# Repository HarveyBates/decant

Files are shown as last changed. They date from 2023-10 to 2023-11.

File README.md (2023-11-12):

# Decant

CAN-to-USB analyser. Designed to plug into existing CAN infrastructure for analysis. Focused on CANopen. UI is a work in progress.

## Hardware

<div>
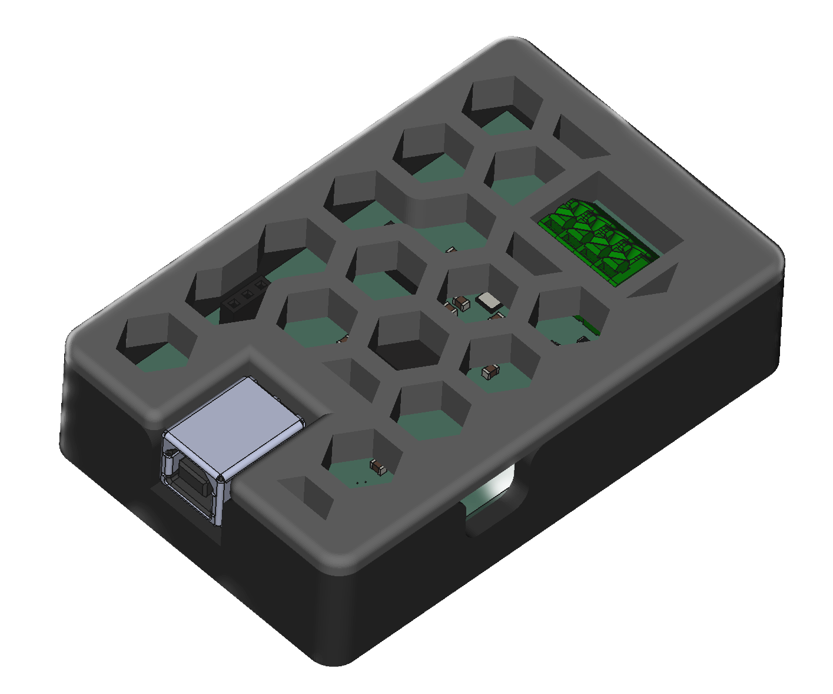
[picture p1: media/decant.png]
  
</div>

### Electronics
- [x] STM32F4 based processor
- [x] Two CAN interfaces with MCP2562 trancievers
- [x] USB powered
- [ ] Breakout other pins for various other functions
- [ ] Reduce footprint

#### BOM
See [BOM](electronics/bom/decant.csv), roughly $40 AUD ($25 USD). Main cost is the processor, however, this is the lowest cost STM32 that features 
CAN and USB on seperate pins.

#### PCB
See `electronics/decant/gerber` for [gerber files](https://github.com/HarveyBates/decant/tree/main/electronics/decant/gerber) 
that can be zipped and uploaded to a PCB manufactuer of choice. Get a top layer stencil too as this will make assembly easier.

## UI

This is a work in progress, currently using [Qt](https://www.qt.io/). Below is a TODO list to make it more functional.

<div>
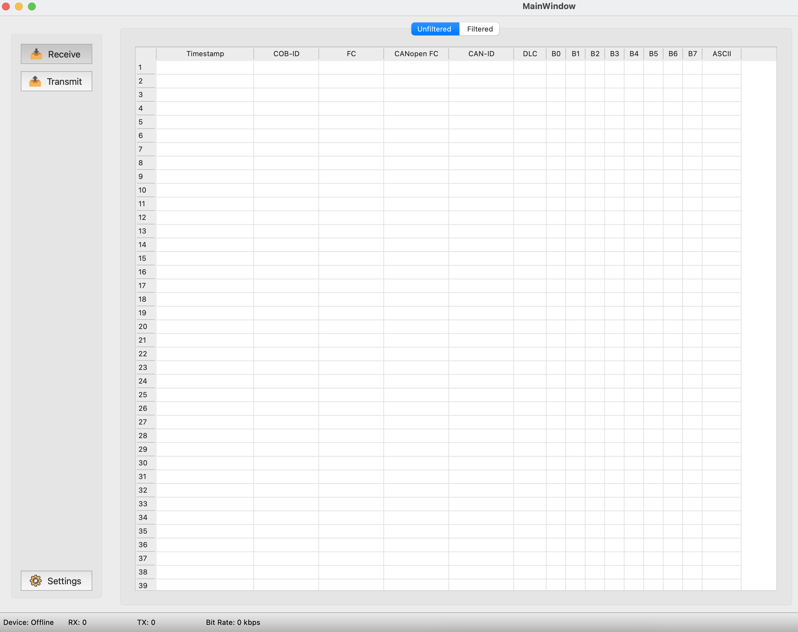
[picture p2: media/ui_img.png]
  
</div>

### Base functions
- [x] Read raw CAN messages to table
- [ ] Filter messages
- [ ] Watch message
- [ ] Inspect bits
- [ ] Inspect message
- [ ] Graph selected bytes

### Database
- [ ] Connect DB
- [ ] Log raw to database
- [ ] Log message to DB (select bytes)

### Grafana 
- [ ] Graph from DB

## Licence
HarveyBates/decant is licensed under the **GNU Affero General Public License v3.0**

Permissions of this strongest copyleft license are conditioned on making available complete source code of licensed works and modifications, which include larger works using a licensed work, under the same license. Copyright and license notices must be preserved. Contributors provide an express grant of patent rights. When a modified version is used to provide a service over a network, the complete source code of the modified version must be made available.

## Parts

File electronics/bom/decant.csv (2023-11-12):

Index | Manufacturer Part Number | Manufacturer Name | Description | Availability | Stock Status | Attrition % | Requested Quantity 1 | Pack Quantity 1 | Pack Type 1 | Digi-Key Part Number 1 | Unit Price 1 | Extended Price 1 | Minimum Order Quantity 1 | Customer Reference | Requested Part Number | Lead Weeks | Datasheet | Part Status | Original Part numbers
1 | C0805C104M5RAC7800 | KEMET | CAP CER 0.1UF 50V X7R 0805 | 878,828 | In Stock |  | 11 | 11 | Cut Tape (CT) | 399-C0805C104M5RAC7800CT-ND | 0.08700 | $0.96 | 1 |  | 399-C0805C104M5RAC7800CT-ND | 19 | https://connect.kemet.com:7667/gateway/IntelliData-ComponentDocumentation/1.0/download/datasheet/C0805C104M5RACTU | Active | 399-C0805C104M5RAC7800CT-ND
2 | CL21A106KOQNNNE | Samsung Electro-Mechanics | CAP CER 10UF 16V X5R 0805 | 4,588,996 | In Stock |  | 3 | 3 | Cut Tape (CT) | 1276-1096-1-ND | 0.16000 | $0.48 | 1 |  | 1276-1096-1-ND | 22 | https://mm.digikey.com/Volume0/opasdata/d220001/medias/docus/609/CL21A106KOQNNNE_Spec.pdf | Active | 1276-1096-1-ND
3 | CL21A475KAQNNNE | Samsung Electro-Mechanics | CAP CER 4.7UF 25V X5R 0805 | 3,502,864 | In Stock |  | 2 | 2 | Cut Tape (CT) | 1276-1244-1-ND | 0.16000 | $0.32 | 1 |  | 1276-1244-1-ND | 22 | https://mm.digikey.com/Volume0/opasdata/d220001/medias/docus/41/CL21A475KAQNNNE_Spec.pdf | Active | 1276-1244-1-ND
4 | CC0805JRNPO9BN250 | YAGEO | CAP CER 25PF 50V C0G/NPO 0805 | 20,136 | In Stock |  | 2 | 2 | Cut Tape (CT) | 311-4233-1-ND | 0.21000 | $0.42 | 1 |  | 311-4233-1-ND | 16 | https://www.yageo.com/upload/media/product/productsearch/datasheet/mlcc/UPY-GP_NP0_16V-to-50V_18.pdf | Active | 311-4233-1-ND
5 | C0805C150K1HAC7800 | KEMET | CAP CER 15PF 100V X8R 0805 | 13,065 | In Stock |  | 2 | 2 | Cut Tape (CT) | 399-C0805C150K1HAC7800CT-ND | 0.16000 | $0.32 | 1 |  | 399-C0805C150K1HAC7800CT-ND | 20 | https://connect.kemet.com:7667/gateway/IntelliData-ComponentDocumentation/1.0/download/datasheet/C0805C150K1HAC7800 | Active | 399-C0805C150K1HAC7800CT-ND
6 | C0805X103K1RAC3316 | KEMET | CAP CER 0805 10NF 100V X7R | 82,350 | In Stock |  | 1 | 1 | Cut Tape (CT) | 399-C0805X103K1RAC3316CT-ND | 0.28000 | $0.28 | 1 |  | 399-C0805X103K1RAC3316CT-ND | 16 | https://connect.kemet.com:7667/gateway/IntelliData-ComponentDocumentation/1.0/download/datasheet/C0805X103K1RAC3316 | Active | 399-C0805X103K1RAC3316CT-ND
7 | C0805C472J3GEC7210 | KEMET | CAP CER 0805 4.7NF 25V C0G 5% | 13,829 | In Stock |  | 1 | 1 | Cut Tape (CT) | 399-C0805C472J3GEC7210CT-ND | 0.36000 | $0.36 | 1 |  | 399-C0805C472J3GEC7210CT-ND | 27 | https://connect.kemet.com:7667/gateway/IntelliData-ComponentDocumentation/1.0/download/datasheet/C0805C472J3GEC7210 | Active | 399-C0805C472J3GEC7210CT-ND
8 | RMCF0805FT120R | Stackpole Electronics Inc | RES 120 OHM 1% 1/8W 0805 | 1,031,088 | In Stock |  | 5 | 5 | Cut Tape (CT) | 738-RMCF0805FT120RCT-ND | 0.16000 | $0.80 | 1 |  | 738-RMCF0805FT120RCT-ND | 17 | https://www.seielect.com/catalog/sei-rmcf_rmcp.pdf | Active | 738-RMCF0805FT120RCT-ND
9 | RMCF0805FT10K0 | Stackpole Electronics Inc | RES 10K OHM 1% 1/8W 0805 | 4,671,376 | In Stock |  | 2 | 2 | Cut Tape (CT) | RMCF0805FT10K0CT-ND | 0.16000 | $0.32 | 1 |  | RMCF0805FT10K0CT-ND | 17 | https://www.seielect.com/catalog/sei-rmcf_rmcp.pdf | Active | RMCF0805FT10K0CT-ND
10 | RMCF0805FT1K00 | Stackpole Electronics Inc | RES 1K OHM 1% 1/8W 0805 | 1,037,673 | In Stock |  | 2 | 2 | Cut Tape (CT) | RMCF0805FT1K00CT-ND | 0.16000 | $0.32 | 1 |  | RMCF0805FT1K00CT-ND | 17 | https://www.seielect.com/catalog/sei-rmcf_rmcp.pdf | Active | RMCF0805FT1K00CT-ND
11 | CRCW0805100RFKEAHP | Vishay Dale | RES SMD 100 OHM 1% 1/2W 0805 | 255,413 | In Stock |  | 1 | 1 | Cut Tape (CT) | 541-100TCT-ND | 0.31000 | $0.31 | 1 |  | 541-100TCT-ND | 28 | https://www.vishay.com/docs/20043/crcwhpe3.pdf | Active | 541-100TCT-ND
12 | LQH3NPN2R2MJRL | Murata Electronics | FIXED IND 2.2UH 980MA 81.6 MOHM | 16,100 | In Stock |  | 1 | 1 | Cut Tape (CT) | 490-9577-1-ND | 0.60000 | $0.60 | 1 |  | 490-9577-1-ND | 19 | https://search.murata.co.jp/Ceramy/image/img/P02/JELF243A-0114.pdf | Active | 490-9577-1-ND
13 | LTST-C171GKT | Lite-On Inc. | LED GREEN CLEAR CHIP SMD | 235,055 | In Stock |  | 2 | 2 | Cut Tape (CT) | 160-1423-1-ND | 0.41000 | $0.82 | 1 |  | 160-1423-1-ND | 18 | https://mm.digikey.com/Volume0/opasdata/d220001/medias/docus/1134/LTST-C171GKT.pdf | Active | 160-1423-1-ND
14 | MCP2562-E/SN | Microchip Technology | IC TRANSCEIVER HALF 1/1 8SOIC | 10,886 | In Stock |  | 2 | 2 | Tube | MCP2562-E/SN-ND | 1.98000 | $3.96 | 1 |  | MCP2562-E/SN-ND | 4 | https://ww1.microchip.com/downloads/en/DeviceDoc/20005167C.pdf | Active | MCP2562-E/SN-ND
15 | USBLC6-2SC6 | STMicroelectronics | TVS DIODE 5.25VWM 17VC SOT23-6 | 65,415 | In Stock |  | 1 | 1 | Cut Tape (CT) | 497-5235-1-ND | 1.00000 | $1.00 | 1 |  | 497-5235-1-ND | 25 | https://www.st.com/content/ccc/resource/technical/document/datasheet/06/1d/48/9c/6c/20/4a/b2/CD00050750.pdf/files/CD00050750.pdf/jcr:content/translations/en.C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 | Active | 497-5235-1-ND
16 | STM32F412RGT6 | STMicroelectronics | IC MCU 32BIT 1MB FLASH 64LQFP | 1,007 | In Stock |  | 1 | 1 | Tray | 497-16764-ND | 17.49000 | $17.49 | 1 |  | 497-16764-ND | 12 | https://www.st.com/content/ccc/resource/technical/document/datasheet/15/90/07/b3/8c/10/4e/95/DM00213872.pdf/files/DM00213872.pdf/jcr:content/translations/en.D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 | Active | 497-16764-ND
17 | TPS63001DRCR | Texas Instruments | IC REG BUCK-BST 3.3V 1.6A 10VSON | 15,952 | In Stock |  | 1 | 1 | Cut Tape (CT) | 296-19643-1-ND | 3.89000 | $3.89 | 1 |  | 296-19643-1-ND | 6 | https://www.ti.com/general/docs/suppproductinfo.tsp?distId=10 | Active | 296-19643-1-ND
18 | TSX-3225 25.0000MF10P-C0 | EPSON | CRYSTAL 25.0000MHZ 18PF SMD | 25,555 | In Stock |  | 1 | 1 | Cut Tape (CT) | SER4211CT-ND | 0.69000 | $0.69 | 1 |  | SER4211CT-ND | 18 | https://support.epson.biz/td/api/doc_check.php?dl=brief_TSX-3225&lang=en | Active | SER4211CT-ND
19 | ECS-.327-12.5-34R-C-TR | ECS Inc. | CRYSTAL 32.7680KHZ 12.5PF SMD | 39,609 | In Stock |  | 1 | 1 | Cut Tape (CT) | XC2127CT-ND | 1.09000 | $1.09 | 1 |  | XC2127CT-ND | 23 | https://ecsxtal.com/store/pdf/ECX_34R.pdf | Active | XC2127CT-ND
20 | PTS810 SJM 250 SMTR LFS | C&K | SWITCH TACTILE SPST-NO 0.05A 16V | 231,444 | In Stock |  | 1 | 1 | Cut Tape (CT) | CKN10502CT-ND | 0.64000 | $0.64 | 1 |  | CKN10502CT-ND | 10 | https://www.ckswitches.com/media/1476/pts810.pdf | Active | CKN10502CT-ND
21 | 2508051027Y1 | Fair-Rite Products Corp. | FERRITE BEAD 1K OHM 0805 1LN | 245,715 | In Stock |  | 1 | 1 | Cut Tape (CT) | 1934-1009-1-ND | 0.16000 | $0.16 | 1 |  | 1934-1009-1-ND | 18 | https://www.fair-rite.com/wp-content/themes/fair-rite/print_product.php?pid=19184 | Active | 1934-1009-1-ND
22 | JS202011JCQN | C&K | SWITCH SLIDE DPDT 300MA 6V | 33,238 | In Stock |  | 1 | 1 | Cut Tape (CT) | CKN10723CT-ND | 1.11000 | $1.11 | 1 |  | CKN10723CT-ND | 8 | https://www.ckswitches.com/media/1422/js.pdf | Active | CKN10723CT-ND
23 | CL21B105KAFNNNE | Samsung Electro-Mechanics | CAP CER 1UF 25V X7R 0805 | 1,159,179 | In Stock |  | 1 | 1 | Cut Tape (CT) | 1276-1066-1-ND | 0.16000 | $0.16 | 1 |  | 1276-1066-1-ND | 22 | https://mm.digikey.com/Volume0/opasdata/d220001/medias/docus/1105/CL21B105KAFNNNE_Spec.pdf | Active | 1276-1066-1-ND
24 | UJ2-BH-1-TH | CUI Devices | CONN RCPT USB2.0 TYPEB 4POS R/A | 76,620 | In Stock |  | 1 | 1 | Tray | 102-3999-ND | 1.03000 | $1.03 | 1 |  | 102-3999-ND | 14 | https://www.cuidevices.com/product/resource/uj2-bh-th.pdf | Active | 102-3999-ND
25 | 1985218 | Phoenix Contact | TERM BLOCK 4POS 45DEG 3.5MM PCB | 242,048 | In Stock |  | 1 | 1 | Bulk | 277-1624-ND | 1.09000 | $1.09 | 1 |  | 277-1624-ND | 13 | https://mm.digikey.com/Volume0/opasdata/d220001/medias/docus/2515/COMBICON Spring-Cage PCB Term. Blocks.pdf | Active | 277-1624-ND
26 | HPH2-A-10-UA | Adam Tech | CONN HEADER VERT 10POS 1.27MM | 5,037 | In Stock |  | 1 | 1 | Bag | 2057-HPH2-A-10-UA-ND | 1.01000 | $1.01 | 1 |  | 2057-HPH2-A-10-UA-ND | 14 | https://app.adam-tech.com/products/download/data_sheet/199942/hph2-a-xx-ua-data-sheet.pdf | Active | 2057-HPH2-A-10-UA-ND

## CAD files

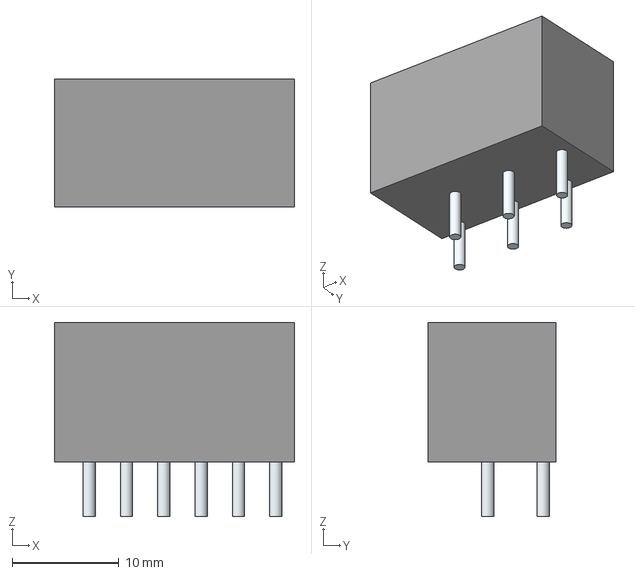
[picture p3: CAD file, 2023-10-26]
electronics/decant/components/extern/3dmodels/connectors/1-2834011-6.stp
22.5 x 12.0 x 18.2 mm
Leads x 6

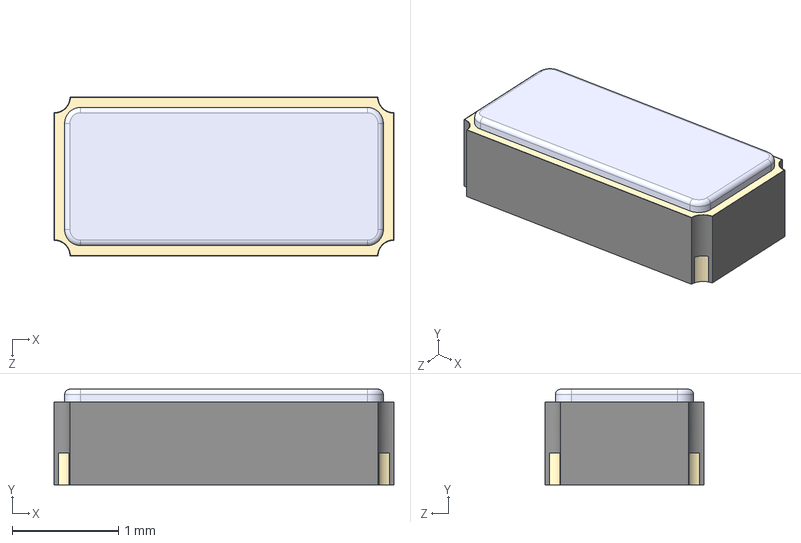
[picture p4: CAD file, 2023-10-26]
electronics/decant/components/extern/3dmodels/crystals/ECS-.327-12.5-34R-C-TR.step
3.20 x 0.9 x 1.50 mm

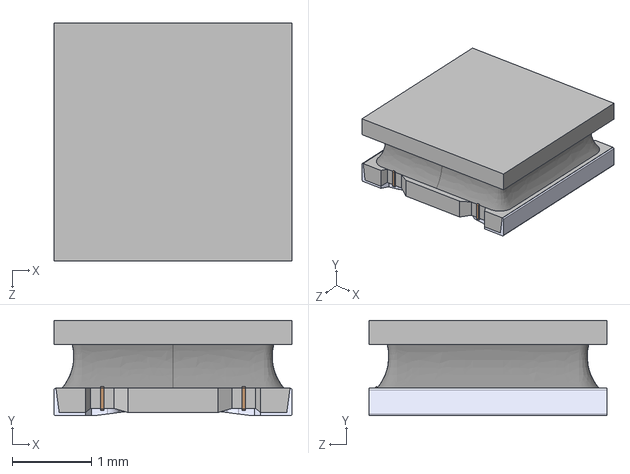
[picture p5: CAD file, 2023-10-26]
electronics/decant/components/extern/3dmodels/inductors/LQH3NPN2R2MJRL.step
3.00 x 1.20 x 3.00 mm

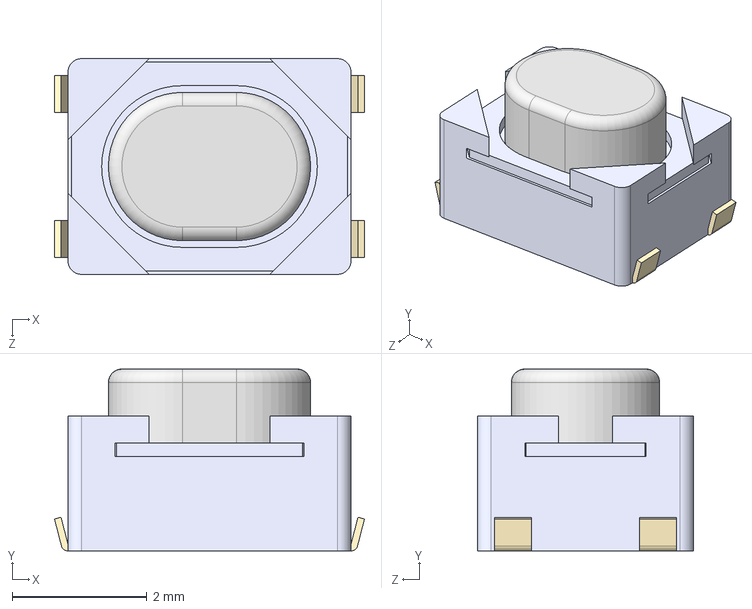
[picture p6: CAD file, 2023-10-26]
electronics/decant/components/extern/3dmodels/tactile-switches/PTS810_SJM_250_SMTR_LFS.step
4.60 x 2.70 x 3.20 mm

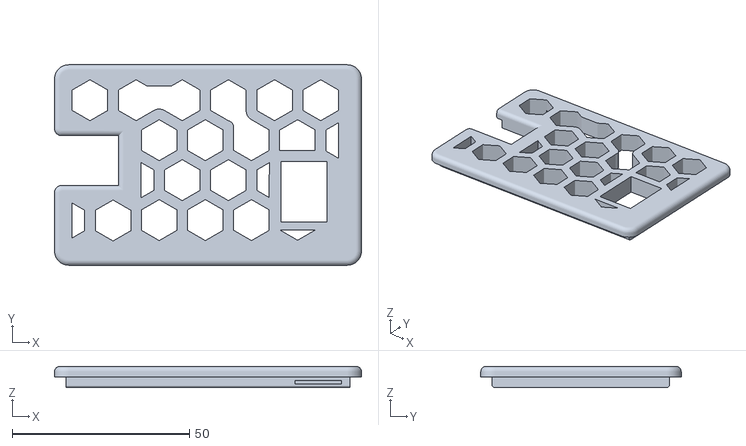
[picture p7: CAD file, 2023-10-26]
models/case/lid.stl
86.5 x 56.5 x 6.00

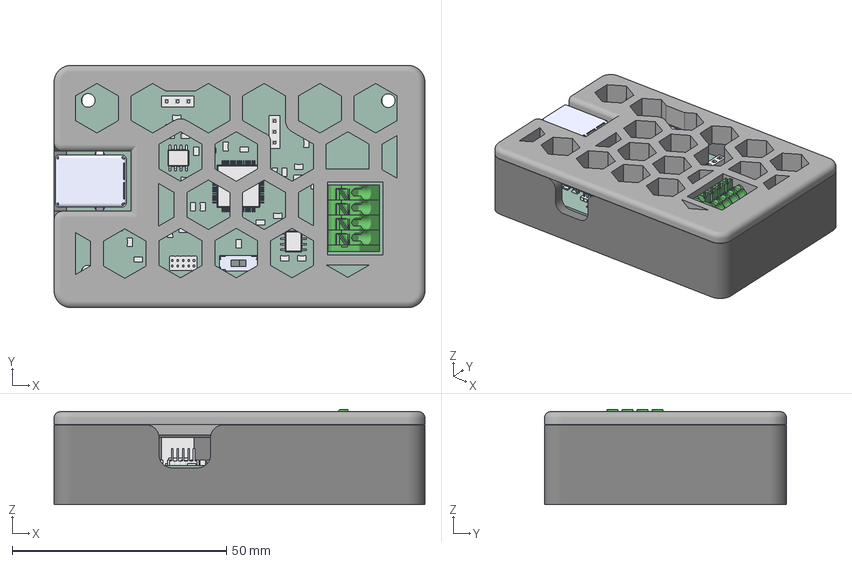
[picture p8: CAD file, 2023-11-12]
models/decant.FCStd
86.5 x 56.5 x 22.3 mm
CAN-Scope PCB
lid

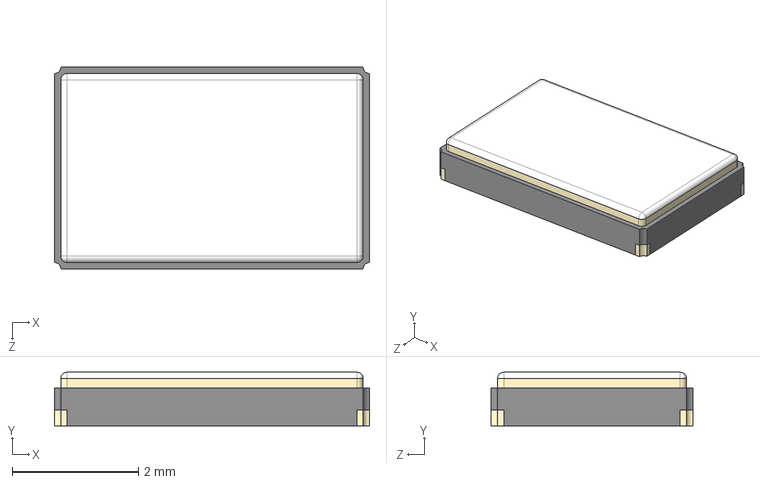
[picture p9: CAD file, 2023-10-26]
electronics/decant/components/extern/3dmodels/crystals/ECS-80-10-30B-CWN-TR.step
5.00 x 0.85 x 3.20 mm

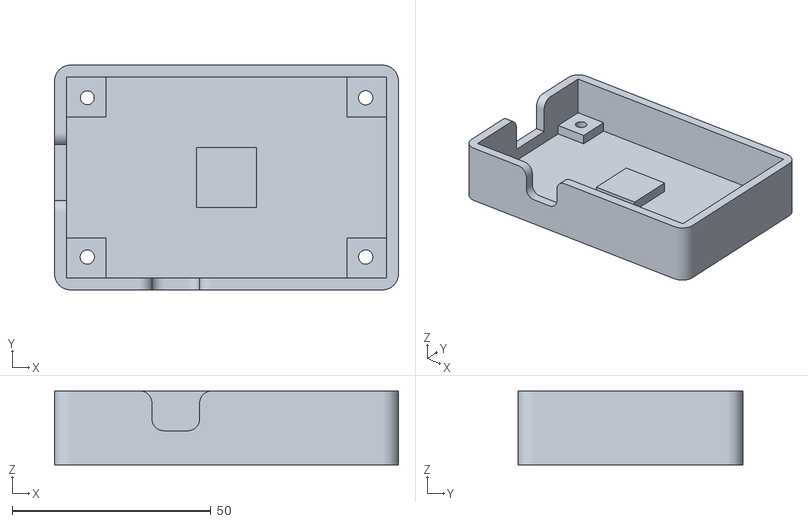
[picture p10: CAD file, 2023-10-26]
models/case/body.stl
86.5 x 56.5 x 18.6

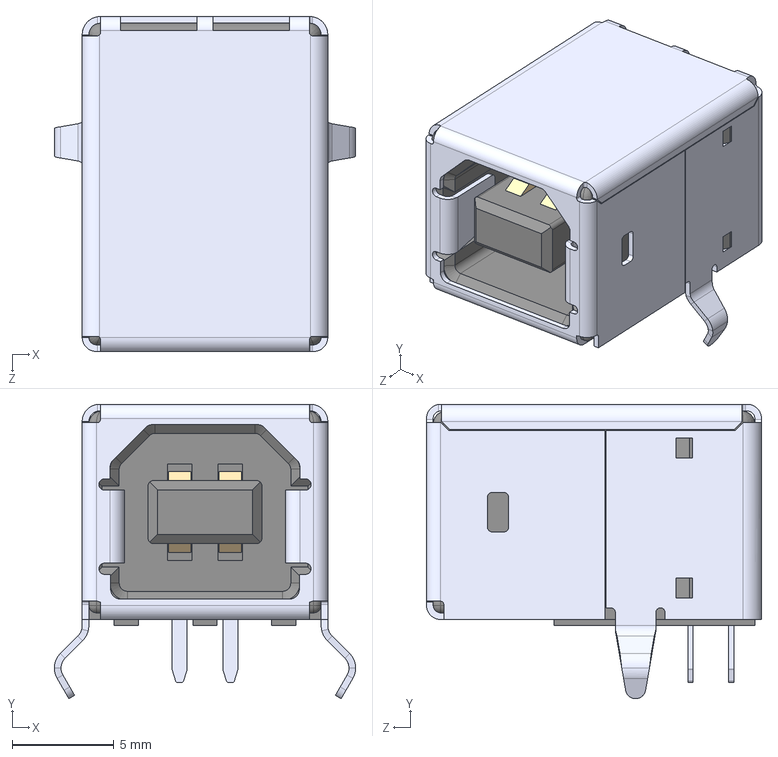
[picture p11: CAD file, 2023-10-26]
electronics/decant/components/extern/3dmodels/connectors/USB-B1HSB6.STEP
14.8 x 14.5 x 16.5 mm

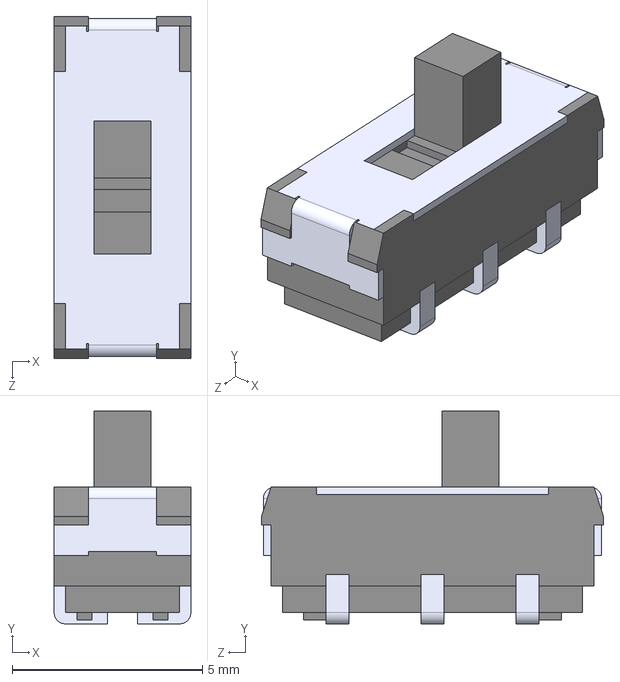
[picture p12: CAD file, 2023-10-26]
electronics/decant/components/extern/3dmodels/switches/JS202011JCQN.step
3.60 x 5.60 x 9.00 mm

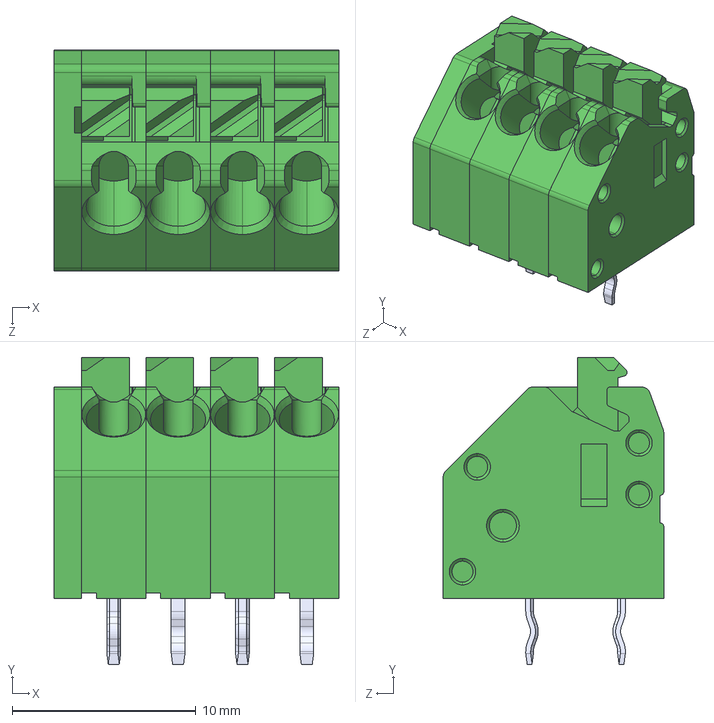
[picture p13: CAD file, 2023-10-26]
electronics/decant/components/extern/3dmodels/connectors/1985218.step
15.5 x 16.7 x 12.0 mm

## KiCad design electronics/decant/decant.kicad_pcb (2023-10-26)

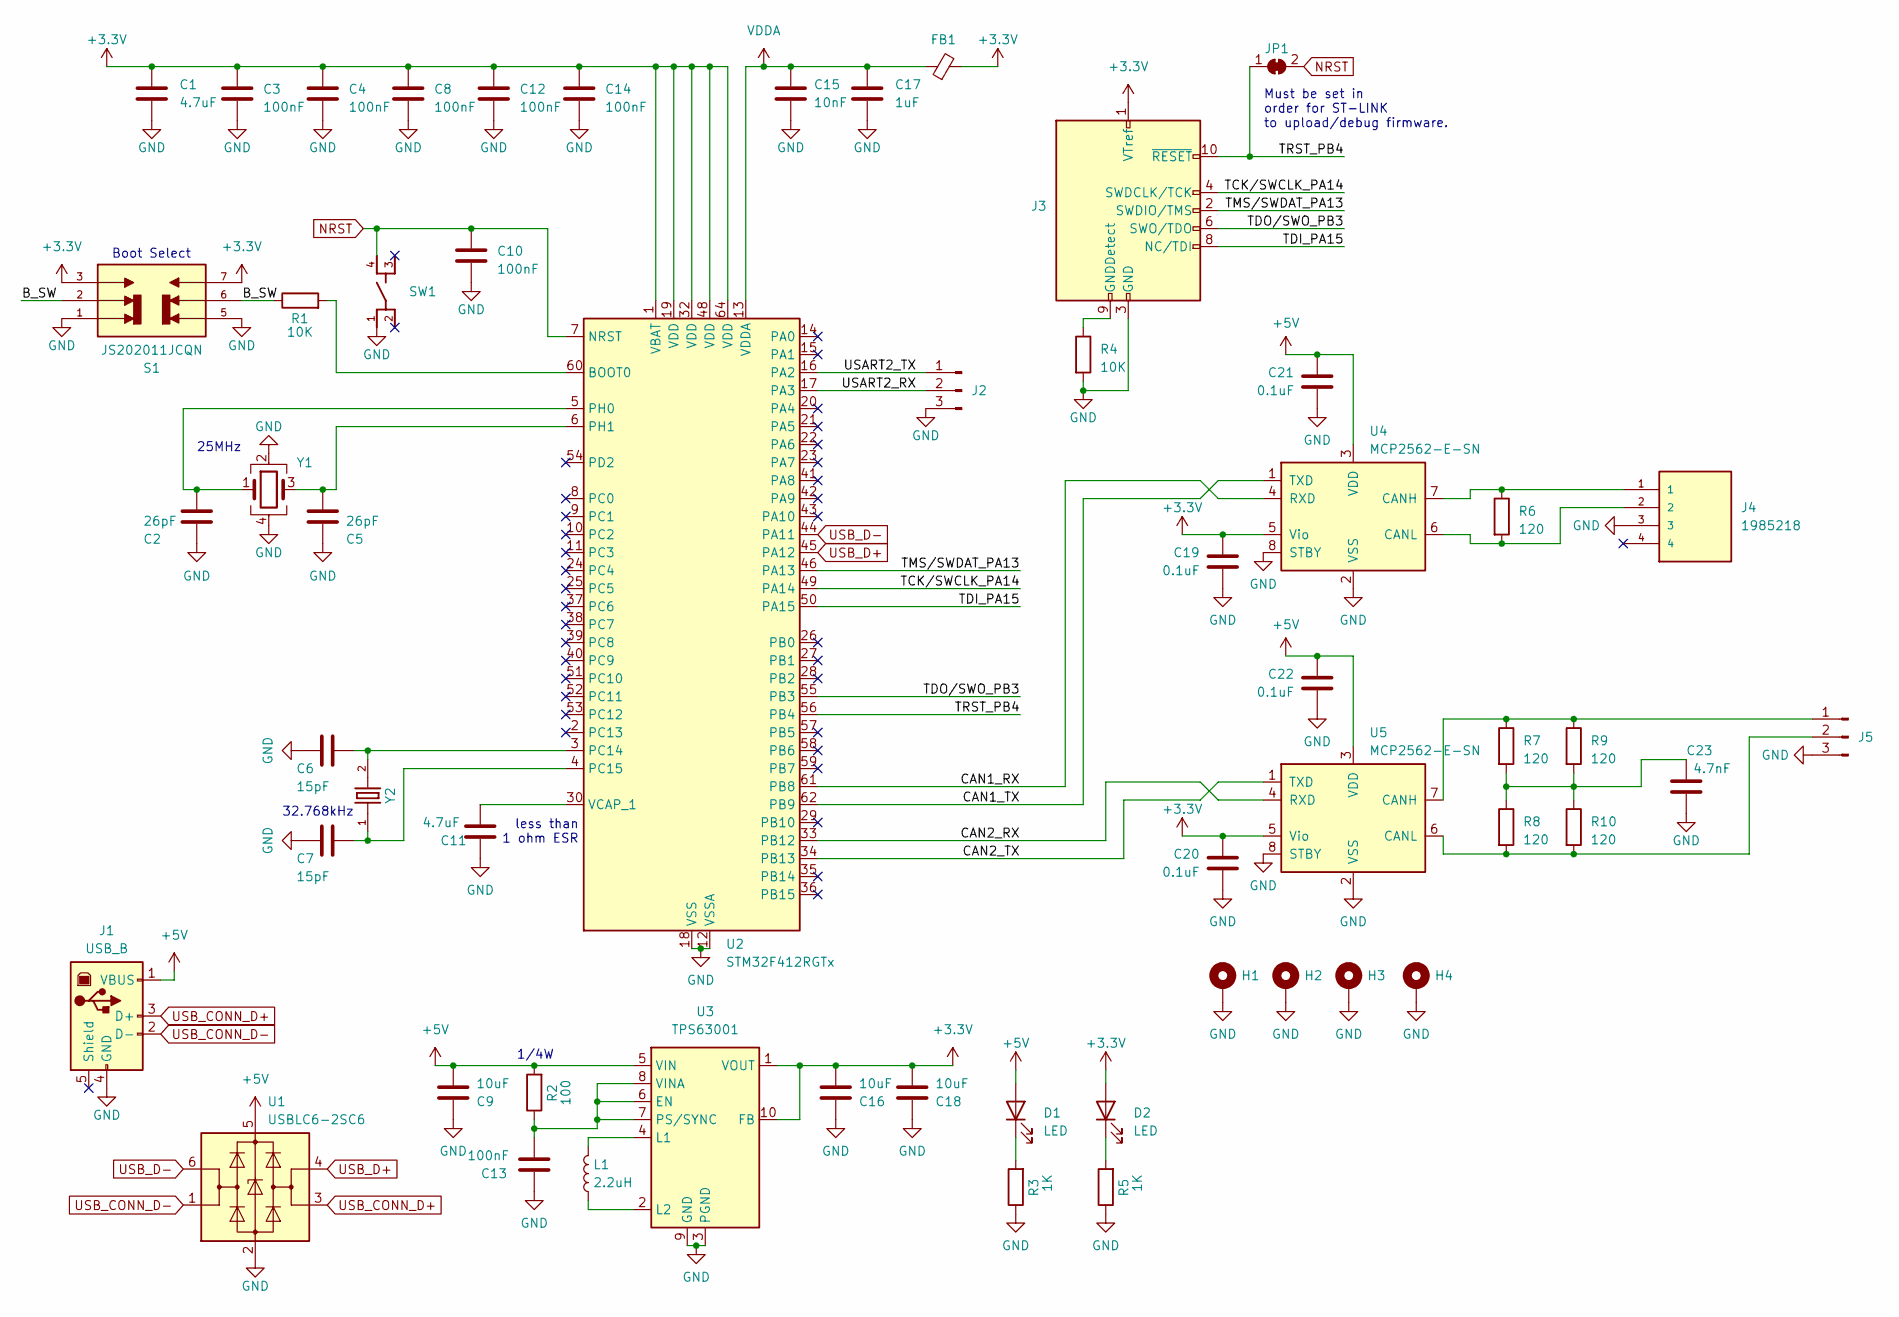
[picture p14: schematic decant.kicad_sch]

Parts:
C1, C11: 4.7uF; C_0805_2012Metric
C2, C5: 26pF; C_0805_2012Metric
C3, C4, C8, C10, C12, C13, C14: 100nF; C_0805_2012Metric
C6, C7: 15pF; C_0805_2012Metric
C9, C16, C18: 10uF; C_0805_2012Metric
C15: 10nF; C_0805_2012Metric
C17: 1uF; C_0805_2012Metric
C19, C20, C21, C22: 0.1uF; C_0805_2012Metric
C23: 4.7nF; C_0805_2012Metric
D1, D2: LED; LED_0805_2012Metric
FB1: FerriteBead_Small; R_0805_2012Metric
H1, H2, H3, H4: MountingHole_Pad; MountingHole_3.2mm_M3_ISO14580_Pad_TopBottom
J1: USB_B; UJ2-BH-1-TH
J2, J5: Conn_01x03_Pin; PinSocket_1x03_P2.54mm_Vertical
J3: Conn_ARM_JTAG_SWD_10; PinHeader_2x05_P1.27mm_Vertical; Part GRPB052VWVN-RC
J4: 1985218; PARTREV 29.03.2021
JP1: SolderJumper-2_P1.3mm_Bridged_Pad1.0x1.5mm
L1: 2.2uH; LQH3NPN2R2MJRL; Part LQH3NPN2R2MJRL
R1, R4: 10K; R_0805_2012Metric
R2: 100; R_0805_2012Metric
R3, R5: 1K; R_0805_2012Metric
R6, R7, R8, R9, R10: 120; R_0805_2012Metric
S1: JS202011JCQN; PARTREV 11 Nov 19
SW1: PTS810_SJM_250_SMTR_LFS
U1: USBLC6-2SC6; SOT-23-6
U2: STM32F412RGTx; LQFP-64_10x10mm_P0.5mm
U3: TPS63001; Texas_DRC0010J_ThermalVias
U4, U5: MCP2562-E-SN; SOIC-8_3.9x4.9mm_P1.27mm
Y1: Crystal_GND24; Crystal_SMD_3225-4Pin_3.2x2.5mm; Part TSX-3225 25.0000MF10P-C0
Y2: ECS-.327-12.5-34R-C-TR; PARTREV 2016

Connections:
+3.3V: C1.1, C3.1, C4.1, C8.1, C12.1, C14.1, C16.1, C18.1, C19.1, C20.1, D2.2 (A), FB1.2, J3.1 (VTref), S1.3, S1.7, U2.1 (VBAT), U2.19 (VDD), U2.32 (VDD), U2.48 (VDD), U2.64 (VDD), U3.1 (VOUT), U3.10 (FB), U4.5 (Vio), U5.5 (Vio)
+5V: C9.1, C21.1, C22.1, D1.2 (A), J1.1 (VBUS), R2.2, U1.5 (VBUS), U3.5 (VIN), U4.3 (VDD), U5.3 (VDD)
/B_SW: R1.1, S1.2, S1.6
/CAN1_RX: U2.61 (PB8), U4.4 (RXD)
/CAN1_TX: U2.62 (PB9), U4.1 (TXD)
/CAN2_RX: U2.33 (PB12), U5.4 (RXD)
/CAN2_TX: U2.34 (PB13), U5.1 (TXD)
/TCK/SWCLK_PA14: J3.4 (SWDCLK/TCK), U2.49 (PA14)
/TDI_PA15: J3.8 (NC/TDI), U2.50 (PA15)
/TDO/SWO_PB3: J3.6 (SWO/TDO), U2.55 (PB3)
/TMS/SWDAT_PA13: J3.2 (SWDIO/TMS), U2.46 (PA13)
/TRST_PB4: J3.10 (~RESET), JP1.1 (A), U2.56 (PB4)
/USART2_RX: J2.2, U2.17 (PA3)
/USART2_TX: J2.1, U2.16 (PA2)
GND: C1.2, C2.2, C3.2, C4.2, C5.2, C6.2, C7.2, C8.2, C9.2, C10.2, C11.2, C12.2, C13.2, C14.2, C15.2, C16.2, C17.2, C18.2, C19.2, C20.2, C21.2, C22.2, C23.2, H1.1, H2.1, H3.1, H4.1, J1.4 (GND), J2.3, J3.3 (GND), J3.5 (GND), J4.3, J5.3, R3.1, R4.2, R5.1, S1.1, S1.5, SW1.1, U1.2 (GND), U2.12 (VSSA), U2.18 (VSS), U2.31 (VSS), U2.47 (VSS), U2.63 (VSS), U3.3 (PGND), U3.9 (GND), U3.11 (PGND), U4.2 (VSS), U4.8 (STBY), U5.2 (VSS), U5.8 (STBY), Y1.2, Y1.4
NRST: C10.1, JP1.2 (B), SW1.4, U2.7 (NRST)
unnamed: C23.1, R7.2, R8.1, R9.2, R10.1
unnamed: D1.1 (K), R3.2
unnamed: D2.1 (K), R5.2
unnamed: J3.9 (GNDDetect), R4.1
unnamed: J5.1, R7.1, R9.1, U5.7 (CANH)
unnamed: J5.2, R8.2, R10.2, U5.6 (CANL)
unnamed: R1.2, U2.60 (BOOT0)
unnamed: C6.1, U2.3 (PC14), Y2.2
unnamed: C7.1, U2.4 (PC15), Y2.1
unnamed: C2.1, U2.5 (PH0), Y1.1
unnamed: C5.1, U2.6 (PH1), Y1.3
unnamed: C11.1, U2.30 (VCAP_1)
unnamed: C13.1, R2.1, U3.6 (EN), U3.7 (PS/SYNC), U3.8 (VINA)
unnamed: L1.2, U3.4 (L1)
unnamed: L1.1, U3.2 (L2)
unnamed: J4.1, R6.1, U4.7 (CANH)
unnamed: J4.2, R6.2, U4.6 (CANL)
USB_CONN_D+: J1.3 (D+), U1.3 (I/O2)
USB_CONN_D-: J1.2 (D-), U1.1 (I/O1)
USB_D+: U1.4 (I/O2), U2.45 (PA12)
USB_D-: U1.6 (I/O1), U2.44 (PA11)
VDDA: C15.1, C17.1, FB1.1, U2.13 (VDDA)

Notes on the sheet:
1/4W
less than 1 ohm ESR
25MHz
32.768kHz
Boot Select
Must be set in order for ST-LINK to upload/debug firmware.

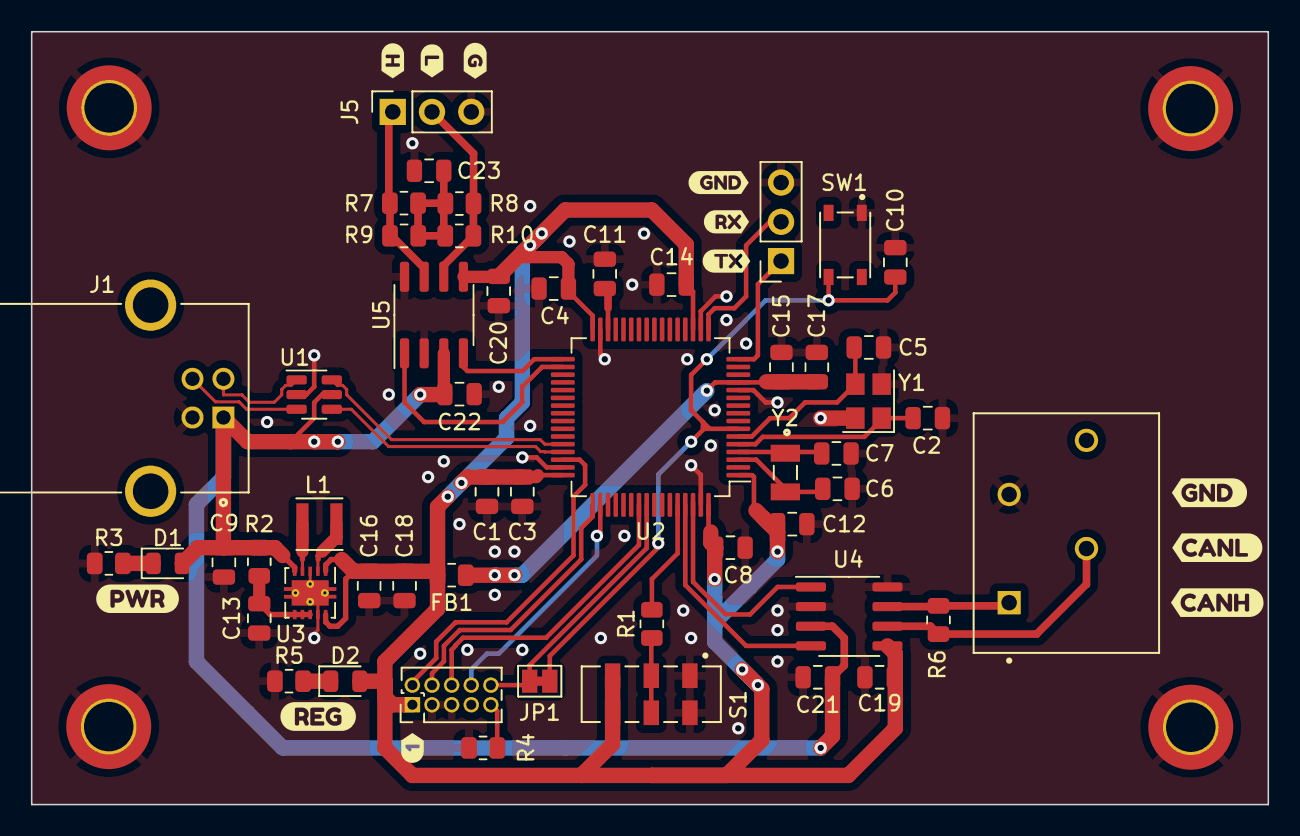
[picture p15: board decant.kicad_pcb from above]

Board: 2 copper layers, 80.0 x 50.0 mm, 68 parts (0 on the bottom side), 38 nets.

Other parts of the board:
kibuzzard-6523D08B: G***; kibuzzard-6523D08B
kibuzzard-6523D09A: G***; kibuzzard-6523D09A
kibuzzard-6523D093: G***; kibuzzard-6523D093
kibuzzard-65247B4E: G***; kibuzzard-65247B4E
kibuzzard-65247B46: G***; kibuzzard-65247B46
kibuzzard-652479A8: G***; kibuzzard-652479A8
kibuzzard-652479B8: G***; kibuzzard-652479B8
kibuzzard-6524744D: G***; kibuzzard-6524744D
kibuzzard-6524799E: G***; kibuzzard-6524799E
kibuzzard-65247965: G***; kibuzzard-65247965
kibuzzard-65247981: G***; kibuzzard-65247981
kibuzzard-65247988: G***; kibuzzard-65247988

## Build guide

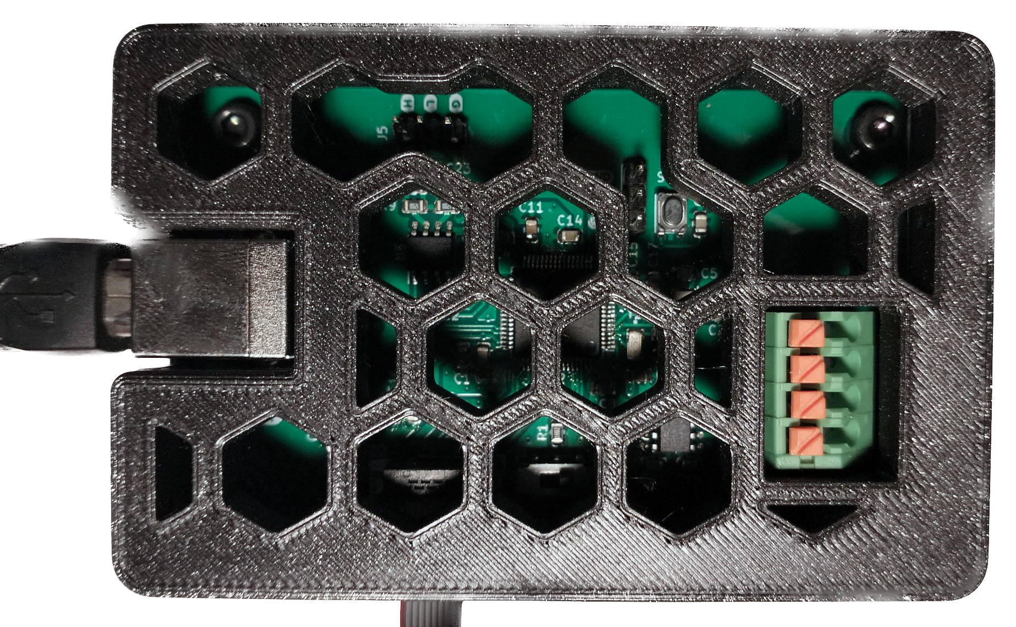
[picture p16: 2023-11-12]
media/decant_assembly.png

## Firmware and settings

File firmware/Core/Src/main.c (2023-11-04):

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
/* Includes ------------------------------------------------------------------*/
#include "main.h"
#include "cmsis_os.h"
#include "usb_device.h"

/* USER CODE BEGIN Includes */
#include "CANopen/canopen_driver.h"

/* USER CODE END Includes */

CAN_HandleTypeDef hcan1;
CAN_HandleTypeDef hcan2;

UART_HandleTypeDef huart2;

/* Definitions for usbTransmit */
osThreadId_t usbTransmitHandle;
const osThreadAttr_t usbTransmit_attributes = {
  .name = "usbTransmit",
  .stack_size = 128 * 4,
  .priority = (osPriority_t) osPriorityAboveNormal,
};
void SystemClock_Config(void);
static void MX_GPIO_Init(void);
static void MX_CAN1_Init(void);
static void MX_CAN2_Init(void);
static void MX_USART2_UART_Init(void);
void StartDefaultTask(void *argument);

/**
  * @brief  The application entry point.
  * @retval int
  */
int main(void)
{
  /* MCU Configuration--------------------------------------------------------*/

  /* Reset of all peripherals, Initializes the Flash interface and the Systick. */
  HAL_Init();

  /* Configure the system clock */
  SystemClock_Config();

  /* Initialize all configured peripherals */
  MX_GPIO_Init();
  MX_CAN1_Init();
  MX_CAN2_Init();
  MX_USART2_UART_Init();
  /* USER CODE BEGIN 2 */
  HAL_UART_Transmit(&huart2, (uint8_t*)"Started", sizeof("Started"), 10);

  /* USER CODE END 2 */

  /* Init scheduler */
  osKernelInitialize();

  /* USER CODE BEGIN RTOS_MUTEX */
  /* add mutexes, ... */
  /* USER CODE END RTOS_MUTEX */

  /* USER CODE BEGIN RTOS_SEMAPHORES */
  /* add semaphores, ... */
  /* USER CODE END RTOS_SEMAPHORES */

  /* USER CODE BEGIN RTOS_TIMERS */
  /* start timers, add new ones, ... */
  /* USER CODE END RTOS_TIMERS */

  /* USER CODE BEGIN RTOS_QUEUES */
  /* add queues, ... */
  /* USER CODE END RTOS_QUEUES */

  /* Create the thread(s) */
  /* creation of usbTransmit */
  usbTransmitHandle = osThreadNew(StartDefaultTask, NULL, &usbTransmit_attributes);

  /* USER CODE BEGIN RTOS_THREADS */
  /* add threads, ... */
  /* USER CODE END RTOS_THREADS */

  /* USER CODE BEGIN RTOS_EVENTS */
  /* add events, ... */
  /* USER CODE END RTOS_EVENTS */

  /* Start scheduler */
  osKernelStart();
  /* We should never get here as control is now taken by the scheduler */
  /* Infinite loop */
  /* USER CODE BEGIN WHILE */
  while (1)
  {
    /* USER CODE END WHILE */

    /* USER CODE BEGIN 3 */
  }
  /* USER CODE END 3 */
}

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
/* USER CODE BEGIN Header_StartDefaultTask */
/**
  * @brief  Function implementing the usbTransmit thread.
  * @param  argument: Not used
  * @retval None
  */
/* USER CODE END Header_StartDefaultTask */
void StartDefaultTask(void *argument)
{
  /* init code for USB_DEVICE */
  MX_USB_DEVICE_Init();
  /* USER CODE BEGIN 5 */
  CANopen_init(&hcan1, &huart2);
  /* Infinite loop */
  for(;;)
  {
    CANopen_Queue_Process();
    osDelay(1);
  }
  /* USER CODE END 5 */
}

/**
  * @brief  Period elapsed callback in non blocking mode
  * @note   This function is called  when TIM6 interrupt took place, inside
  * HAL_TIM_IRQHandler(). It makes a direct call to HAL_IncTick() to increment
  * a global variable "uwTick" used as application time base.
  * @param  htim : TIM handle
  * @retval None
  */
void HAL_TIM_PeriodElapsedCallback(TIM_HandleTypeDef *htim)
{
  if (htim->Instance == TIM6) {
    HAL_IncTick();
  }
}

/**
  * @brief  This function is executed in case of error occurrence.
  * @retval None
  */
void Error_Handler(void)
{
  /* USER CODE BEGIN Error_Handler_Debug */
  /* User can add his own implementation to report the HAL error return state */
  __disable_irq();
  HAL_UART_Transmit(&huart2, (uint8_t*)"ERROR", sizeof("ERROR"), 10);
  while (1)
  {
  }
  /* USER CODE END Error_Handler_Debug */
}

#ifdef  USE_FULL_ASSERT
/**
  * @brief  Reports the name of the source file and the source line number
  *         where the assert_param error has occurred.
  * @param  file: pointer to the source file name
  * @param  line: assert_param error line source number
  * @retval None
  */
void assert_failed(uint8_t *file, uint32_t line)
{
  /* USER CODE BEGIN 6 */
  /* User can add his own implementation to report the file name and line number,
     ex: printf("Wrong parameters value: file %s on line %d\r\n", file, line) */
  /* USER CODE END 6 */
}
#endif /* USE_FULL_ASSERT */

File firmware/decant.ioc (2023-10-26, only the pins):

Mcu.UserName=STM32F412RGTx
PA11.Signal=USB_OTG_FS_DM
PA12.Signal=USB_OTG_FS_DP
PA13.Signal=SYS_JTMS-SWDIO
PA14.Signal=SYS_JTCK-SWCLK
PA15.Signal=SYS_JTDI
PA2.Signal=USART2_TX
PA3.Signal=USART2_RX
PB12.Signal=CAN2_RX
PB13.Signal=CAN2_TX
PB3.Signal=SYS_JTDO-SWO
PB4.Signal=SYS_JTRST
PB8.Signal=CAN1_RX
PB9.Signal=CAN1_TX
PC14-OSC32_IN.Signal=RCC_OSC32_IN
PC15-OSC32_OUT.Signal=RCC_OSC32_OUT

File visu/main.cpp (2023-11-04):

#include <QApplication>

#include "usb/usb_handler.h"
#include "windows/mainwindow.h"

int main(int argc, char* argv[]) {
  QApplication app(argc, argv);

  spdlog::set_level(spdlog::level::debug);

  // Reduce font size
  QFont defaultFont = QApplication::font();
  defaultFont.setPointSize(11);
  QApplication::setFont(defaultFont);

  // Setup USB RX thread
  USBHandlerThread usb_rx_thread;
  usb_rx_thread.start();

  // Show main window
  MainWindow w;
  w.show();

  // Start UI
  int res = QApplication::exec();

  // Cleanup threads
  usb_rx_thread.stop();
  usb_rx_thread.wait();

  return res;
}

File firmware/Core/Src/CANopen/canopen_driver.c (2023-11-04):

#include "canopen_driver.h"

CAN_HandleTypeDef* hcan;
#ifdef CANOPEN_DEBUG
UART_HandleTypeDef* huart;
#endif

const uint8_t QUEUE_SIZE = 16;

/// CAN Message
typedef struct {
  CAN_RxHeaderTypeDef header;
  uint8_t data[8]; // CAD-FD has 64 bytes (handle later on)
} CANopenMessage;

/// Queue of received messages
osMessageQueueId_t rxQueue;

CANopenStatus CANopen_apply_filters();

uint32_t create_cob_id(CANopenFunctionCode FC, uint32_t CAN_ID) {
  return (uint32_t)FC | CAN_ID;
}

#ifdef CANOPEN_DEBUG
CANopenStatus CANopen_init(CAN_HandleTypeDef* _hcan, UART_HandleTypeDef* _huart) {
  if (!_huart) return CANOPEN_ERR;
  huart = _huart;
#else
  CANopenStatus CANopen_init(CAN_HandleTypeDef* _hcan) {
#endif

  CANopenStatus can_status;
  HAL_StatusTypeDef hal_status;

  if (!_hcan) return CANOPEN_ERR;
  hcan = _hcan;

  can_status = CANopen_apply_filters();
  if (can_status != CANOPEN_OK) {
    return can_status;
  }

  hal_status = HAL_CAN_Start(hcan);
  if (hal_status != HAL_OK) {
    return CANOPEN_START_ERR;
  }

  hal_status = HAL_CAN_ActivateNotification(hcan, CAN_IT_RX_FIFO0_MSG_PENDING);
  if (hal_status != HAL_OK) {
    return CANOPEN_RX_CB_SETUP_ERR;
  }

  // Setup FreeRTOS message queue
  rxQueue = osMessageQueueNew(QUEUE_SIZE, sizeof(CANopenMessage), NULL);
  if (!rxQueue) {
    return CANOPEN_QUEUE_INIT_ERR;
  }

  return CANOPEN_OK;
}

CANopenStatus CANopen_apply_filters() {
  CAN_FilterTypeDef filter;

  // Default filter, accepts all messages
  filter.FilterBank = 0;
  filter.FilterMode = CAN_FILTERMODE_IDMASK;
  filter.FilterFIFOAssignment = CAN_RX_FIFO0;
  filter.FilterIdHigh = 0;
  filter.FilterIdLow = 0;
  filter.FilterMaskIdHigh = 0;
  filter.FilterMaskIdLow = 0;
  filter.FilterScale = CAN_FILTERSCALE_32BIT;
  filter.FilterActivation = ENABLE;
  filter.SlaveStartFilterBank = 14;

  if (HAL_CAN_ConfigFilter(hcan, &filter) != HAL_OK) {
    return CANOPEN_FILTER_ERR;
  }

  return CANOPEN_OK;
}

// Transmit
CANopenStatus CANopen_Transmit(const CANopenFunctionCode FC,
                               const uint32_t NODE_ID,
                               const uint8_t* data,
                               uint8_t data_size) {
  CAN_TxHeaderTypeDef   tx_header;
  uint8_t               tx_data[8];
  uint32_t              tx_mailbox;

  tx_header.IDE = CAN_ID_STD;
  tx_header.StdId = create_cob_id(FC, NODE_ID);
  tx_header.RTR = CAN_RTR_DATA;
  tx_header.DLC = data_size;

  // Constrain data size to <= 8
  data_size = (data_size > 8) ? 8 : data_size;

  for (uint8_t i = 0; i < data_size; i++) {
    tx_data[i] = data[i];
  }

  if (HAL_CAN_AddTxMessage(hcan, &tx_header, tx_data, &tx_mailbox) != HAL_OK) {
    return CANOPEN_TX_ERR;
  }

  return CANOPEN_OK;
}

// Receive via interrupt
void HAL_CAN_RxFifo0MsgPendingCallback(CAN_HandleTypeDef* _hcan) {
  CANopenMessage msg;

  if (HAL_CAN_GetRxMessage(_hcan, CAN_RX_FIFO0, &msg.header, msg.data) != HAL_OK) {
    Error_Handler();
    return;
  }

  // Put message in queue
  osMessageQueuePut(rxQueue, &msg, 0U, 0U);
}

void CANopen_Queue_Process() {
  CANopenMessage msg;
  osStatus_t status;

  // Get a message off the queue if available
  status = osMessageQueueGet(rxQueue, &msg, NULL, 0U);

  if (status !=  osOK) {
    return;
  }

  // Transmit this message over USB
  CDC_Transmit_FS((uint8_t *)&msg, sizeof(msg));
}

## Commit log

2023-10-26 initial commit with visu, firmware and electronics
    [1-2834011-6.stp, 1985218.step, ECS-.327-12.5-34R-C-TR.step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]
2023-11-04 switch from imgui to qt
2023-11-04 added filtered table, untested yet
2023-11-11 working on filtered table and bit inspector
    [decant.kicad_sch]
2023-11-12 added media and models
    [decant.FCStd]
2023-11-12 added bom
    [decant.csv]

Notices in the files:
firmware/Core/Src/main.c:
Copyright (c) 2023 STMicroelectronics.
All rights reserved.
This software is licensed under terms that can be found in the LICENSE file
